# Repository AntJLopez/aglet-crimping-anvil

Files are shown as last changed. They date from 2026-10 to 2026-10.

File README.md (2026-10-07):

# Aglet Crimping Anvil

Parametric crimping anvil for making metal-tubing shoelace aglets, based on the custom aglet crimping anvil on Ian Fieggen's Shoelace Site: https://www.fieggen.com/shoelace/agletmetal.htm

<p>
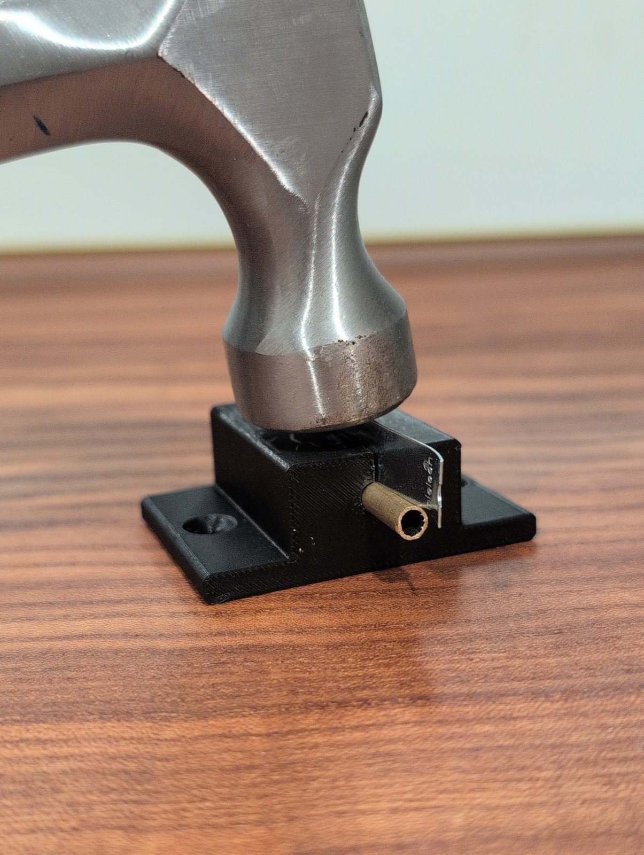
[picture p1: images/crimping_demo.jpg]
Brass tubing in the anvil's hole with the chisel in the slot, under a hammer
  
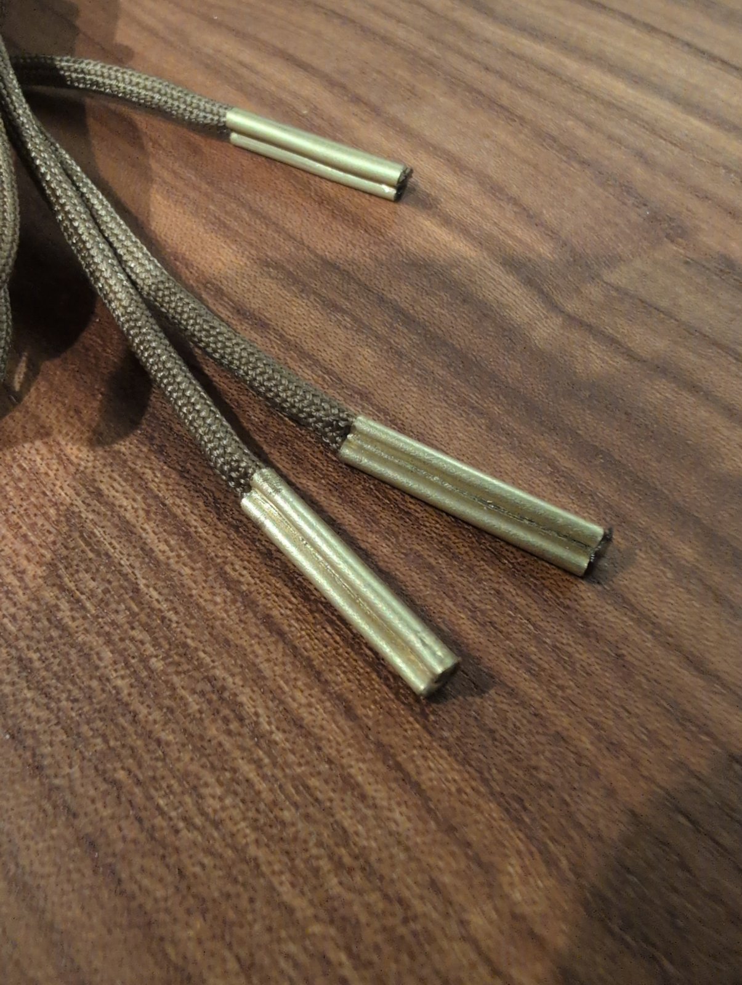
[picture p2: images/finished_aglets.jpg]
Finished brass aglets crimped onto paracord laces
  
</p>

Slide brass, copper or aluminium tubing over the lace end, feed it into the hole, set a thin steel strip (the "chisel") in the slot, and tap it gently with a hammer to crimp the tube lengthwise onto the lace.

Customizable: tubing diameter and hole clearance, chisel thickness and slot clearance, slot depth, block size, and an optional bench-mounting flange with countersinks for #8 or M4 flat-head screws. Defaults: 5.0 mm tubing, 0.45 mm chisel, 5 mm slot depth, and a 40 × 30 × 20 mm block (length × width × height).

<p>
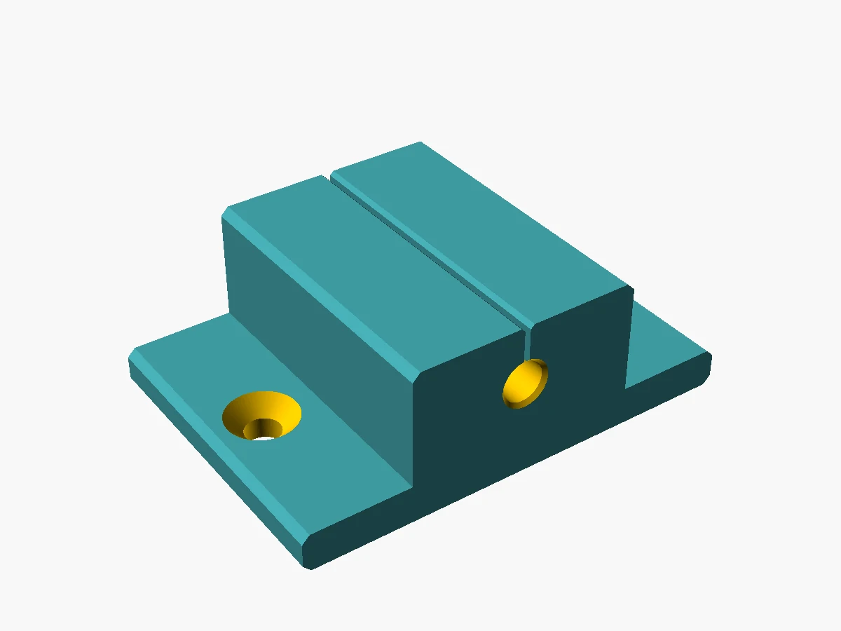
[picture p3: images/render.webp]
Render of the anvil at the default settings
  
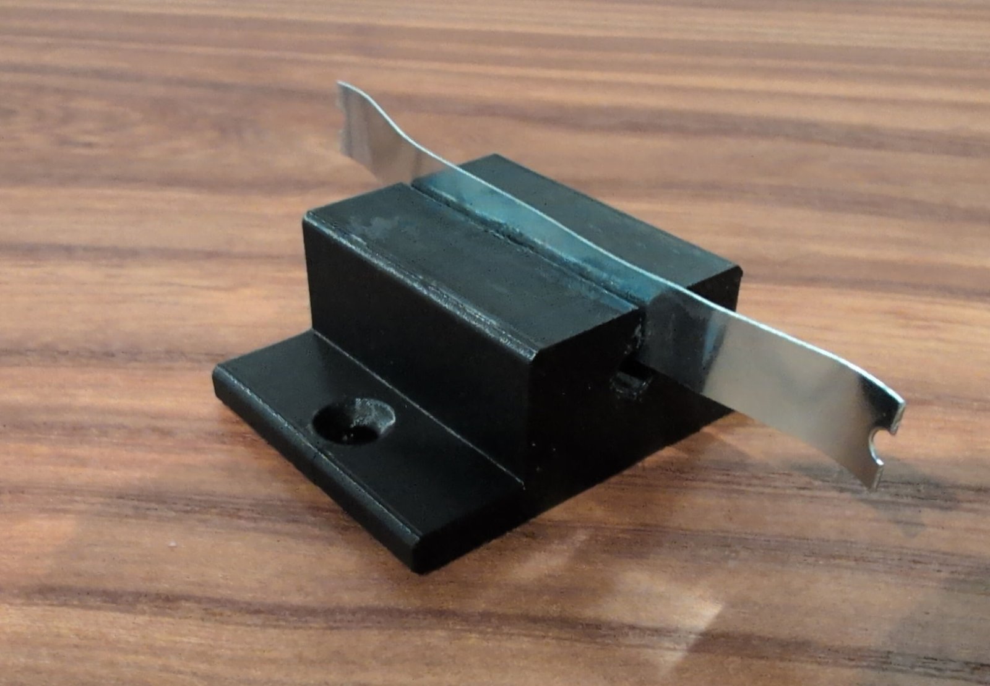
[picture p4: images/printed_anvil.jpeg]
Printed anvil with a steel strip in the slot
  
</p>

Customize in your browser: [open the model in OpenSCAD Playground](https://ochafik.com/openscad2/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), with nothing to install. Or download the .scad, open it in OpenSCAD, and change the parameters in the Customizer panel (Window > Customizer).

Examples: the examples folder has ready-to-print STLs for 4, 5 and 6 mm tubing, all with a 0.45 mm chisel and the other defaults.

Printing: print as exported, standing on end with the hole vertical. The crimping forces then push along the layers instead of pulling them apart, and the hole prints round. No supports needed. 100% infill recommended. PLA works well because it is stiffer than PETG.

Fit: holes and slots usually print 0.1 to 0.2 mm small, and the 0.3 mm default clearances allow for that. If the tubing binds, ream the hole with a drill bit of the tubing's size.

Use: screw it down through the flange or clamp the flange. Don't clamp the block across its width in a vise, which squeezes the slot shut. Use a chisel with a straight, slightly rounded edge.

Tested with: [5 mm OD brass tubing](https://www.mcmaster.com/88605K24/) from McMaster-Carr on [Atwood Rope 7-strand mil-spec 550 paracord](https://atwoodrope.com/products/7-strand-paracord-mil-spec), with an anvil printed in PLA at 100% infill. The chisel was a scrap steel strip about 0.4 mm thick, a spring clip like those in [Nielsen metal frame hardware kits](https://www.metroframe.com/nielsen-metal-hardware/). It bent after a few aglets, so a hardened spring-steel strip of similar thickness, such as a feeler-gauge blade, should last longer. Leaving only a few millimeters of the strip above the block also helps keep it from bending.

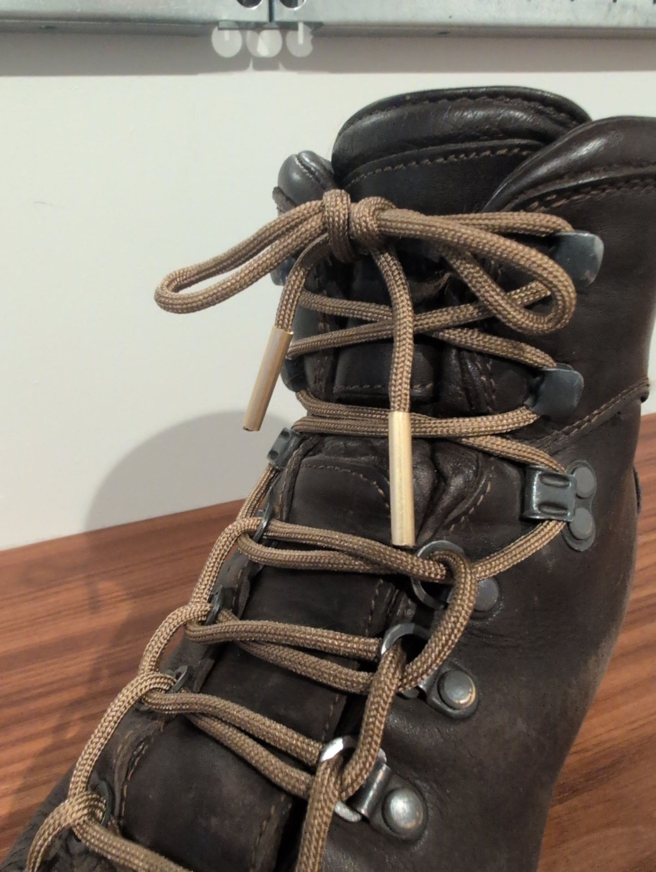
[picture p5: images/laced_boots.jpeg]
Boots laced with the finished aglets


Modeled in OpenSCAD with AI assistance (Anthropic's Claude); test-printed and used by me. Source .scad included.

License: CC BY 4.0 (see LICENSE). If you share or remix this design, credit Antonio J. López and link to this repository.

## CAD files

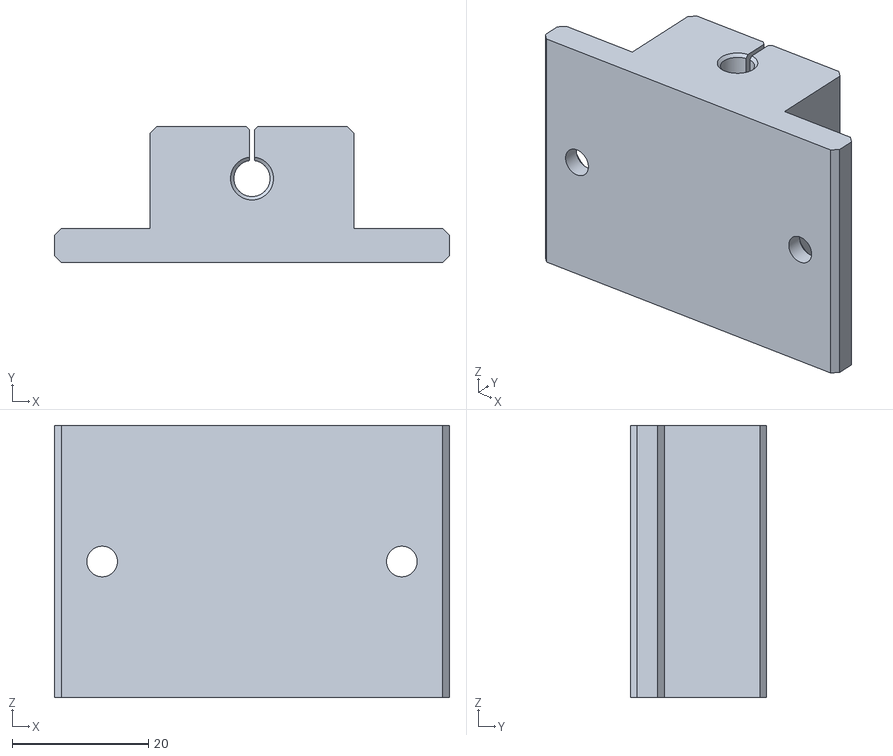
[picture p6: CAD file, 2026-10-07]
examples/aglet_crimping_anvil_5mm.stl
58.0 x 20.0 x 40.0

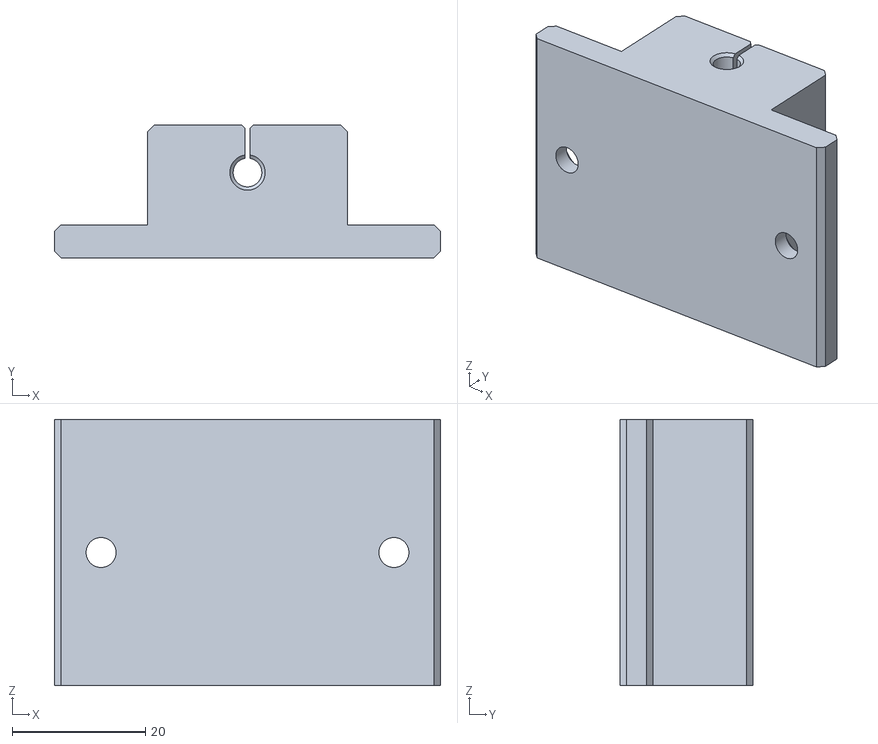
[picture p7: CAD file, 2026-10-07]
examples/aglet_crimping_anvil_4mm.stl
58.0 x 20.0 x 40.0

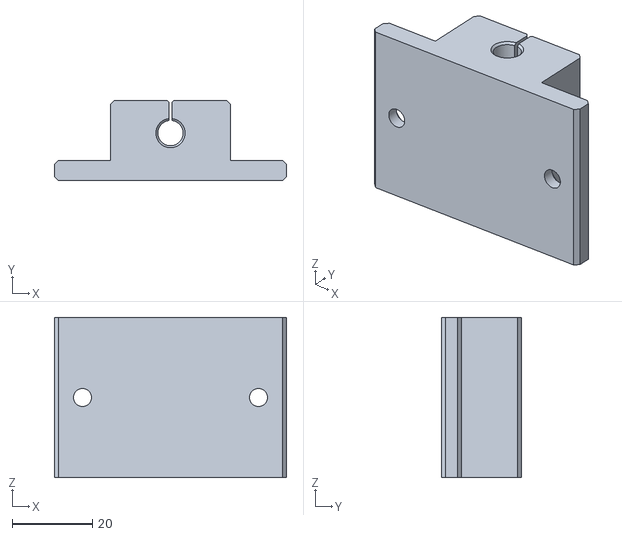
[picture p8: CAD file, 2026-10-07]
examples/aglet_crimping_anvil_6mm.stl
58.0 x 20.0 x 40.0

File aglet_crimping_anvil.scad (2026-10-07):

// Aglet crimping anvil
//
// Parametric model of the aglet crimping anvil described on Ian's Shoelace Site:
// https://www.fieggen.com/shoelace/agletmetal.htm
//
// A block with a hole through it holds metal tubing slipped over a shoelace end,
// and a slot from the top face down into the hole guides a thin metal chisel.
// Tapping the chisel with a hammer crimps the tubing lengthwise onto the shoelace.
//
// All dimensions are in millimeters. Change the parameters in the Customizer panel
// (Window > Customizer), render with F6, then export with File > Export.

/* [Tubing hole] */

// Outer diameter of the tubing (1/8 in = 3.18, 5/32 in = 3.97, 3/16 in = 4.76).
tubing_outer_diameter = 5.0; // [1:0.01:12]

// Added to the tubing diameter to size the hole. Raise it if the tubing binds.
hole_clearance = 0.3; // [0:0.05:1]

// Size of the 45-degree chamfer at each end of the hole.
hole_entry_chamfer = 0.5; // [0:0.1:2]

/* [Chisel slot] */

// Thickness of the thin metal chisel.
chisel_thickness = 0.45; // [0.2:0.05:3]

// Added to the chisel thickness to size the slot. Raise it if the chisel binds.
slot_clearance = 0.3; // [0:0.05:1]

// Depth of the slot, from the top face down to the hole.
slot_depth = 5; // [2:0.5:40]

// Size of the 45-degree lead-in chamfer where the slot meets the top face.
slot_entry_chamfer = 0.5; // [0:0.1:2]

/* [Anvil block] */

// Length of the block along the hole. Make it at least as long as the aglet.
anvil_length = 40; // [10:1:100]

// Width of the block across the hole.
anvil_width = 30; // [10:1:100]

// Height of the block, from the bench to the top face.
anvil_height = 20; // [10:1:100]

// Size of the 45-degree chamfer on the outer edges that run along the hole.
outer_edge_chamfer = 1.0; // [0:0.25:5]

/* [Mounting flange] */

// Add a base flange with countersunk screw holes for fastening to a bench.
mounting_flange_enabled = true;

// Distance the flange extends past each side of the block.
mounting_flange_width = 14; // [6:0.5:40]

// Thickness of the flange.
mounting_flange_thickness = 5; // [2:0.5:15]

// Diameter of the screw clearance holes (4.5 fits #8 and M4 screws).
mounting_screw_diameter = 4.5; // [2:0.1:8]

// Head diameter of the flat-head screws, which sit in 90-degree countersinks.
mounting_screw_head_diameter = 9.0; // [3:0.1:16]

/* [Orientation] */

// Stand the anvil on end with the hole vertical, the strongest print orientation.
orient_for_printing = true;

/* [Hidden] */

// Hole diameter and slot width, including clearance.
hole_diameter = tubing_outer_diameter + hole_clearance;
slot_width = chisel_thickness + slot_clearance;

// Height of the hole axis above the bottom face.
hole_center_height = anvil_height - slot_depth - hole_diameter / 2;

// Material left below the hole and on each side of it.
floor_thickness = anvil_height - slot_depth - hole_diameter;
side_wall_thickness = (anvil_width - hole_diameter) / 2;

// Width of the whole part, including the flange when it is enabled.
overall_width = mounting_flange_enabled
    ? anvil_width + 2 * mounting_flange_width
    : anvil_width;

// Smallest outer dimension that a corner chamfer has to fit within.
smallest_outer_dimension = mounting_flange_enabled
    ? min(anvil_width, anvil_height, mounting_flange_thickness)
    : min(anvil_width, anvil_height);

// Distance from the center of the anvil to each mounting screw.
mounting_screw_offset = (anvil_width + mounting_flange_width) / 2;

// Depth of each screw countersink.
countersink_depth = (mounting_screw_head_diameter - mounting_screw_diameter) / 2;

// Smallest wall allowed below and beside the hole.
minimum_wall_thickness = 2;

// Smallest gap allowed between a countersink and the edges of the flange.
minimum_countersink_margin = 1;

// Overlap that keeps boolean operations free of coincident faces.
epsilon = 0.01;

// Segment count of the hole and its chamfers.
hole_fragments = 96;

// Resolution of all other curves.
$fa = 1;
$fs = 0.2;

// Parameter checks

assert(
    slot_width < hole_diameter,
    "slot_width must be smaller than hole_diameter, or the tubing is unsupported."
);
assert(
    floor_thickness >= minimum_wall_thickness,
    str(
        "Only ", floor_thickness, " mm of material is left below the hole. ",
        "Increase anvil_height or reduce slot_depth."
    )
);
assert(
    side_wall_thickness >= minimum_wall_thickness,
    "Increase anvil_width to leave material on both sides of the hole."
);
assert(
    2 * outer_edge_chamfer < smallest_outer_dimension,
    "Reduce outer_edge_chamfer so that it fits the block and the flange."
);
if (mounting_flange_enabled) {
    assert(
        mounting_screw_head_diameter > mounting_screw_diameter,
        "The screw head must be larger than the screw clearance hole."
    );
    assert(
        countersink_depth < mounting_flange_thickness,
        "Increase mounting_flange_thickness to fit the screw countersinks."
    );
    assert(
        mounting_flange_width
            >= mounting_screw_head_diameter + 2 * minimum_countersink_margin,
        "Increase mounting_flange_width to fit the screw countersinks."
    );
}

// Rectangle centered on the origin, with 45-degree chamfers on all four corners.
//
// Args:
//   size: Width and height of the rectangle, as [x, y].
//   chamfer: Leg length of each corner chamfer. Zero gives square corners.
module chamfered_rectangle(size, chamfer) {
    half_width = size[0] / 2;
    half_height = size[1] / 2;
    if (chamfer > 0) {
        polygon([
            [-half_width + chamfer, -half_height],
            [half_width - chamfer, -half_height],
            [half_width, -half_height + chamfer],
            [half_width, half_height - chamfer],
            [half_width - chamfer, half_height],
            [-half_width + chamfer, half_height],
            [-half_width, half_height - chamfer],
            [-half_width, -half_height + chamfer]
        ]);
    } else {
        square(size, center = true);
    }
}

// Outline of the block and the optional flange, before the hole and slot are cut.
module anvil_outline() {
    translate([0, anvil_height / 2])
        chamfered_rectangle([anvil_width, anvil_height], outer_edge_chamfer);
    if (mounting_flange_enabled) {
        translate([0, mounting_flange_thickness / 2])
            chamfered_rectangle(
                [overall_width, mounting_flange_thickness], outer_edge_chamfer
            );
    }
}

// Cross-section of the chisel slot, including the lead-in at the top face.
//
// The slot starts at the hole axis so that it opens fully into the hole. Below the
// top of the hole, it only overlaps material that the hole already removes.
module chisel_slot_outline() {
    lead_in_half_width = slot_width / 2 + slot_entry_chamfer + epsilon;
    translate([-slot_width / 2, hole_center_height])
        square([slot_width, anvil_height - hole_center_height + epsilon]);
    if (slot_entry_chamfer > 0) {
        polygon([
            [-lead_in_half_width, anvil_height + epsilon],
            [lead_in_half_width, anvil_height + epsilon],
            [slot_width / 2, anvil_height - slot_entry_chamfer],
            [-slot_width / 2, anvil_height - slot_entry_chamfer]
        ]);
    }
}

// Cross-section of the anvil perpendicular to the hole, with the slot cut out.
//
// X spans the width of the anvil, and Y rises from the bottom face to the top face,
// where the slot opens.
module anvil_profile() {
    difference() {
        anvil_outline();
        chisel_slot_outline();
    }
}

// Hole that holds the tubing, with a 45-degree chamfer at each end.
//
// A single solid of revolution puts the bore and its chamfers on shared vertices,
// which keeps zero-area faces out of the exported mesh.
module tubing_hole() {
    hole_radius = hole_diameter / 2;
    flared_radius = hole_radius + hole_entry_chamfer + epsilon;
    translate([0, hole_center_height, 0])
        rotate_extrude($fn = hole_fragments)
            polygon([
                [0, -epsilon],
                [flared_radius, -epsilon],
                [hole_radius, hole_entry_chamfer],
                [hole_radius, anvil_length - hole_entry_chamfer],
                [flared_radius, anvil_length + epsilon],
                [0, anvil_length + epsilon]
            ]);
}
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

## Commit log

2026-10-07 Add SCAD source
    [aglet_crimping_anvil.scad]
2026-10-07 Add examples and render image
    [aglet_crimping_anvil_4mm.stl, aglet_crimping_anvil_5mm.stl, aglet_crimping_anvil_6mm.stl]
2026-10-07 Link to OpenSCAD Playground, use Unix line endings
    [aglet_crimping_anvil.scad]
